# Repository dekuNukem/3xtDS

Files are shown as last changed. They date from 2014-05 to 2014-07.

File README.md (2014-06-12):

3xtDS
=====

The 3DS Streaming Console with External Control Interface, or 3xtDS, is a modified Nintendo 3DS console equipped with an capture card and an USB interface that allows the control of buttons, circle pad, and touch screen from an external source, as well as streaming high quality video of the content of both screen and sound back to the host to be recorded, or broadcast. This allows some very interesting applications such as interactive streaming on Twitch or other websites, gameplay automation, remote play over Internet, using alternative controllers, and much more.

Please see a short video of it in action: https://www.youtube.com/watch?v=9PZrJH7Z8KE

I want to thank u/velocikoopa for providing a console for me to work on, without him this project would be impossible.

Project gallery: http://imgur.com/a/ICxh5

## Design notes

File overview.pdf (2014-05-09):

# 3DS Streaming Console with External Control Interface

# Technical overview

## 1. Introduction

The 3DS Streaming Console with External Control Interface, or 3xtDS in short, is a modified Nintendo 3DS console equipped with an capture card and an USB interface that allows the control of buttons, circle pad, and touch screen from an external source, as well as streaming high quality video of the content of both screen and sound back to the host to be recorded, or broadcasted. This allows some very interesting applications such as interactive streaming on Twitch or other websites, gameplay automation, remote play over internet, using alternative controllers, and much more.

The construction of this project is relatively straight forward. A 3DS with capture card is taken apart, various contacts to the buttons, circle pad, and touchscreen is then brought out to be controlled by a microcontroller, who executes commands from USB serial communication.

Please note that this document is just a brief overview of several aspects of this project, not a step-by-step guide of making one from scratch. Unless you have some decent experience with analog/digital circuits, microcontroller programming, taking stuff apart and being able to put it back together again, I would not encourage you trying creating one yourself, since you’ll most likely break a expensive piece of gaming console.

## 2. Hardware Overview

The hardware aspect of this project is relatively simple: just take a 3DS apart and solder some wires on some test points. But first of all you have to obtain a 3DS with a capture card. One was kindly lent to be by Reddit user velocikoopa, and it was him that made the entire project possible. You can buy a new one, but it’s rather expensive. velocikoopa paid almost $600 for his 3DS with capture card. A much cheaper capture card-enhanced 2DS is coming out at $380. Although I haven’t seen it in person yet. (http://www.3dsvideocapture.com/product/40)

Before we start, something to keep in mind: Don’t forget to bring out the ground of the 3DS and connect it to your own circuit, otherwise 3DS will not respond to the control signals. And also 3DS uses 1.8V logic, so whenever I mention VCC it’s 1.8V.

Follow iFixit’s teardown (http://www.ifixit.com/Teardown/Nintendo+3DS+Teardown/5029) until you have the mother board out, be careful as there are a lot of small components and fragile ZIF flat cables. Look for buttons’ test points on the front side of the motherboard, namely TP85 for up, TP87 for left, TP91 for down, TP90 for right (this might be under the flat cable for the capture card, cut a little opening to access this test point), TP81 for select and TP80 for start. Three of the test points for A, B, X, Y are right in the middle of those four buttons, the other one is right above Y button. There is no test point for home button, but you can just solder a wire on the left pin of the button. Here is a picture of all the wires soldered in place:

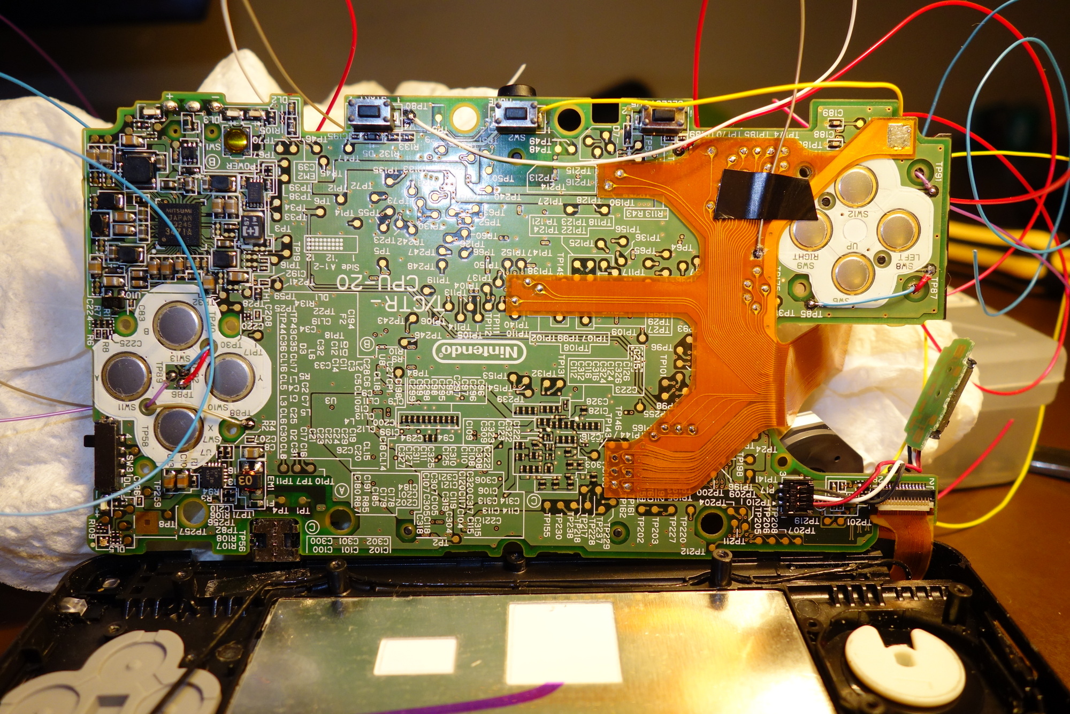
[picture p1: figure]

There are no test points for L and R shoulder buttons either. I soldered wire directly to each button itself, on the middle pin:

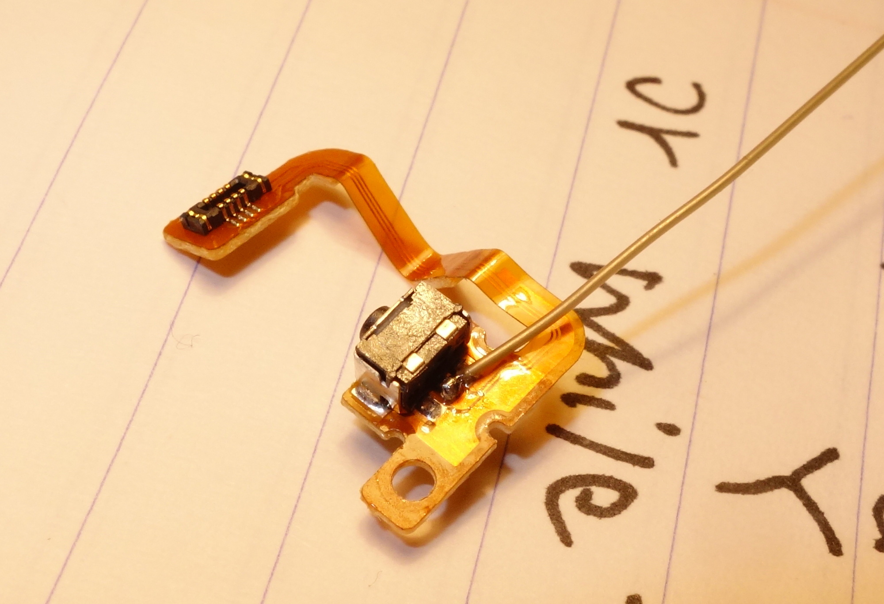
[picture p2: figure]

Now onto the circle pad. It is basically an potentiometer with two outputs, one for each axis. When looking at this picture:

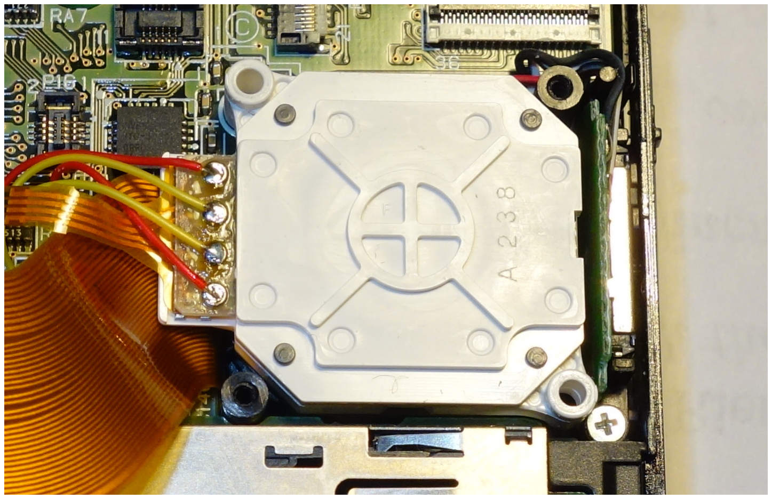
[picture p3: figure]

The pinout from top to bottom is: GND, x potential, VCC, y potential. To control the circle pad with microcontroller, simply desolder the potential output wires and feed them the DAC output from microcontroller instead. Range is from 0V to VCC.

Everything so far has been pretty trivial, buttons and circle pad. But now we face the biggest challenge: tricking 3DS into thinking someone is using the touch screen. 3DS uses a standard 4-wire interface, to get a general idea of how resistive touch screens work, I suggest taking a look at this document:

http://www.ti.com/lit/an/slaa384a/slaa384a.pdf

As with the method described in Section 1.3 the document:

3DS drives Y+ to VCC, Y- to ground, and measure the output at X+ for X coordinate. Similarly, driving X+ to VCC and X- to ground yield Y coordinate at Y+. To get a complete reading of X

Y–

Read X+

Y+ | Read Y+
X– | X+

VDrive

Figure 3. 4-Wire Touch Coordinate Reading and Y coordinate, X+, X-, Y+, Y- are rapidly switched between input and output, at around 200Hz.

I suggest getting a extra 4-pin flat cable so that you can interface with the touch screen input on the motherboard without destroying the socket:

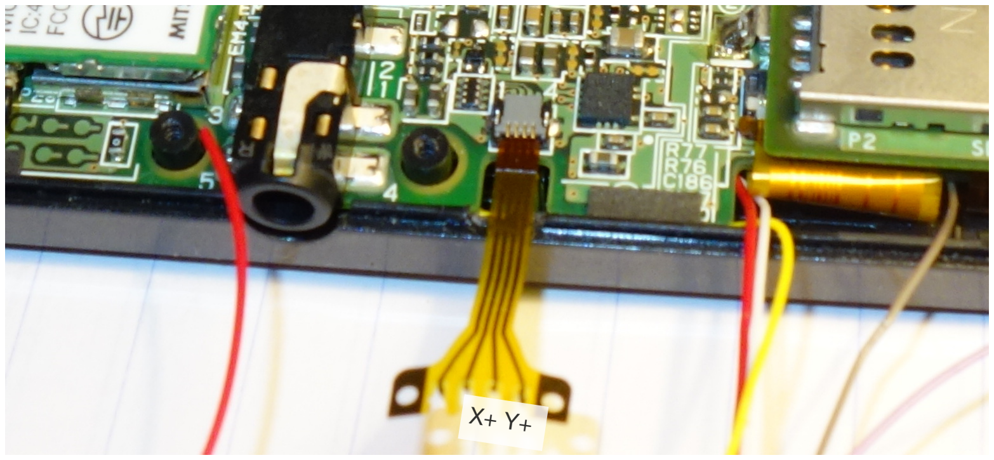
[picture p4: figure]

We only need the last two pins on the right in order to simulate a touch screen for 3DS, they are X+ and Y+ respectively.

The reading of the touch screen is interrupt based, as described in Section 1.2 of the document. Y+ pin is normally at VCC, which is pulled to ground when a touch occurs, generating a touch interrupt, and starting the sampling process.

To write X coordinates, you can tie the DAC output of microcontroller directly to X+ pin in series with a 10K resistor, so when X+ is in input mode, the DAC voltage is read, and when X+ is in output mode, the resistor prevents the current flow. Write 0V to 1.8V for coordinate 0 to 320.

For Y coordinates, the Y+ pin is tricker, since it also generates an interrupt, so some timing is required. After connecting it to DAC in series of a 1K resistor, pull it to ground to initiate touch interrupt, then monitor this pin using an on-board ADC. Once the Y+ pin has been switched to output (reading X coordinate), wait 500 microseconds, so now Y+ is in input mode, then write the Y coordinate to Y+ using the DAC, hold for 200 microseconds, then pull it down to ground again. Write 0V to 1.8V for coordinate 0 to 240.

The timing should look like this:

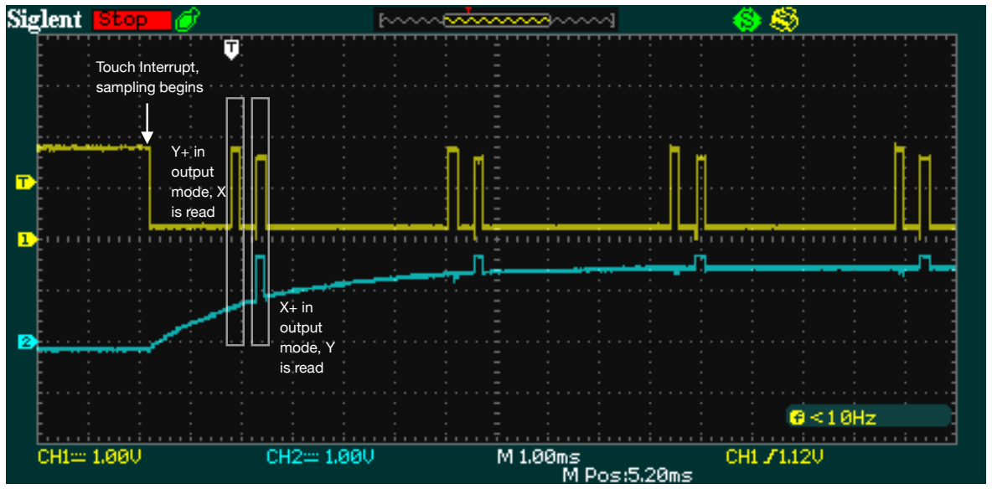
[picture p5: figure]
Touch Interrupt, sampling begins; X+ in output mode, Y is read; Y+ in output mode, X is read

Yellow is Y+, blue is X+

Now you have all the control wires of 3DS, all that’s left to do is hook them up to an microcontroller and have it control it for you! Please take a look at the eagle file for the control board.

## 3. The Control Board

All the wires that came out of 3DS end up in the control board, let at the mercy of the microcontroller, in this case a Teensy 3.1. You can use plain old Arduino as well, but make sure it has enough pins. Also notes that USB serial on Arduino is not as fast as 12Mbit/s full speed USB serial on Teensy 3.1.

The size of the board is quite large for what it is, I did this because of the limitation of the milling machine I’m using, so do feel free to shrink it down.

The circuit for the control board is pretty straightforward as well. All the buttons are active low, so pull them to ground to press them. One problem is the logic levels. 3DS uses 1.8V, while teensy uses 3.3V. I used a 74540 buffer as a level shifter. Power the chip with 1.8V, send 3.3V signal in, 1.8V signal comes out of the other end, and to 3DS.

Teensy 3.1 has a real DAC on A14, as well as a number of PWM pins. I used the real DAC to control the Y+ of touch screen, since it requires very fast response. PWM output can be filtered to create a DAC as well, albeit the tradeoff between rise time and high frequency component left in the output. I used 4 PWM DACs for circle pad X, circle pad Y, touch screen X(hence the slow rise time in blue channel in the above picture), as well as powering the logic switching chip.

I have also added a header for SPI and hardware serial pins, should you need to use those communication protocols.

## 3. Commands

Command | Example | Notes
cn x y | cn 127 200 | Circle pad nudge. Pushes circle pad to x, y, hold it there for c_pad_nudge_delay_ms, then release. x, y should be less than 255 and greater than 0. 127 is neutral position, greater than 127 for left/up, smaller than 127 for right/down.
ch x y | ch 20 127 | Circle pad hold. Hold circle pad at x, y. x, y range is same as circle pad nudge.
cr | cr | Circle pad release. Return circle pad to default location.
cd c_pad_nudge_delay_ms | cd 200 | Circle pad set nudge delay. Set how long the circle pad is held before being released when circle pad nudge is called.
tc x y | tc 133 70 | Touch screen click. Press down on touch screen at x, y, hold it there for touch_screen_click_delay_ms, then release. x should be within 320 y should be within 240

td touch_screen_click_delay_ms | td 200 | Touch screen set click delay. Set how long the touch screen is held before releasing when touch screen click is called.
bc [button] | bc a | Button click. Press down a button, hold it for button_click_delay_ms, then release. See next table for argument of buttons.
bh [button] | bh a | Button hold. Press down a button
br [button] | br a | Button release. Release a button
br | br | Button release all. Release all buttons. Note that this command has no arguments.
bd button_click_delay_ms | bd 100 | Button set click delay. Set how long a button is held down before being released when button click is called.
3DS Button | Argument for bc, bh and br:
A | a
B | b
X | x
Y | y
D-Pad Up | u
D-Pad Down | d
D-Pad Left | l
D-Pad Right | r
Left Shoulder | ls

Right Shoulder | rs
Start | st
Select | sl
Home | h

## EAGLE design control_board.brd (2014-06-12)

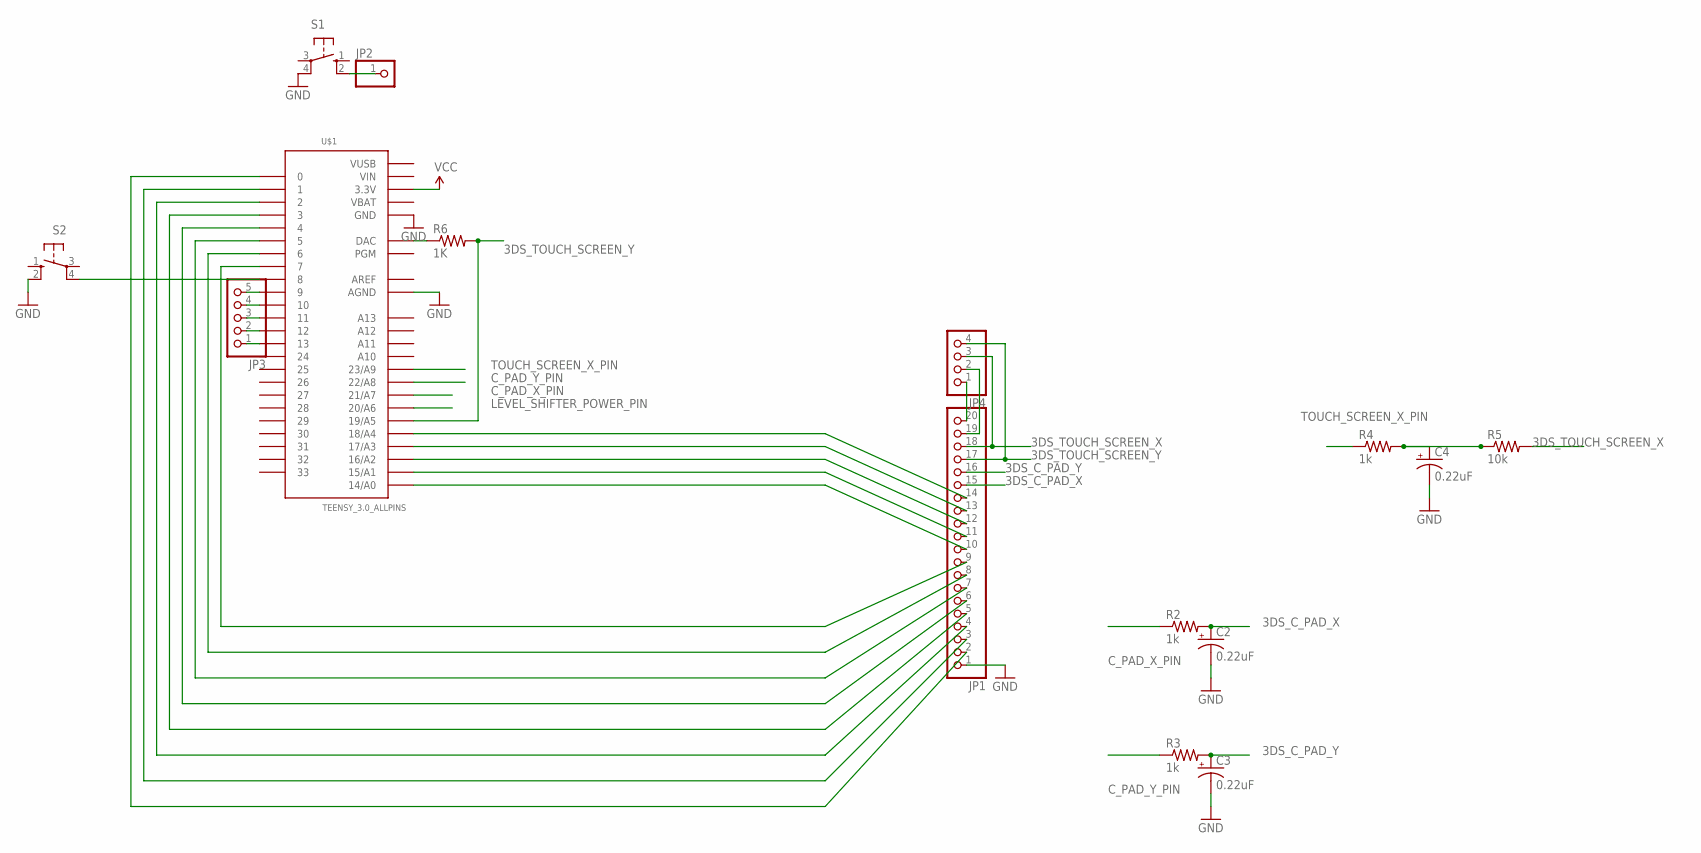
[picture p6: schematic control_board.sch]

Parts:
C2, C3, C4: 0.22uF; CPOL-RADIAL-10UF-25V
JP1: PINHD-1X20; 1X20
JP2: PINHD-1X1; 1X01
JP3: PINHD-1X5; 1X05
JP4: PINHD-1X4; 1X04
R2, R3, R4: 1k; 0207/7
R5: 10k; AXIAL-0.1
R6: 1K; 0207/7
S1, S2: 10-XX; B3F-10XX
U$1: TEENSY_3.0_ALLPINS

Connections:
3DS_C_PAD_X: C2.1 (+), JP1.15, R2.2
3DS_C_PAD_Y: C3.1 (+), JP1.16, R3.2
3DS_TOUCH_SCREEN_X: JP1.18, JP4.3, R5.P$2 (2)
3DS_TOUCH_SCREEN_Y: JP1.17, JP4.4, R6.2, U$1.19/A5
AREF: U$1.AREF
C_PAD_X_PIN: R2.1, U$1.21/A7
C_PAD_Y_PIN: R3.1, U$1.22/A8
GND: C2.2 (-), C3.2 (-), C4.2 (-), JP1.1, S1.4 (P1), S2.2 (S1), U$1.AGND, U$1.GND, U$1.GND1 (GND), U$1.GND2 (GND)
LEVEL_SHIFTER_POWER_PIN: U$1.20/A6
N0: C4.1 (+), R4.2, R5.P$1 (1)
unnamed: JP2.1, S1.2 (S1)
unnamed: JP1.10, U$1.14/A0
unnamed: JP1.11, U$1.15/A1
unnamed: JP1.12, U$1.16/A2
unnamed: JP1.13, U$1.17/A3
unnamed: JP1.2, U$1.0
unnamed: JP1.3, U$1.1
unnamed: JP1.4, U$1.2
unnamed: JP1.5, U$1.3
unnamed: JP1.6, U$1.4
unnamed: JP1.7, U$1.5
unnamed: JP1.8, U$1.6
unnamed: JP1.9, U$1.7
unnamed: R6.1, U$1.RESET (DAC)
unnamed: JP1.14, U$1.18/A4
unnamed: JP3.5, U$1.9
unnamed: JP3.4, U$1.10
unnamed: JP3.3, U$1.11
unnamed: JP3.2, U$1.12
unnamed: JP3.1, U$1.13
unnamed: JP1.20, JP4.1
unnamed: JP1.19, JP4.2
unnamed: S2.4 (P1), U$1.8
TOUCH_SCREEN_X_PIN: R4.1, U$1.23/A9
VBAT: U$1.VBAT
VCC: U$1.3.3V, U$1.3.3V1 (3.3V), U$1.3.3V2 (3.3V)
VIN: U$1.VIN
VUSB: U$1.VUSB

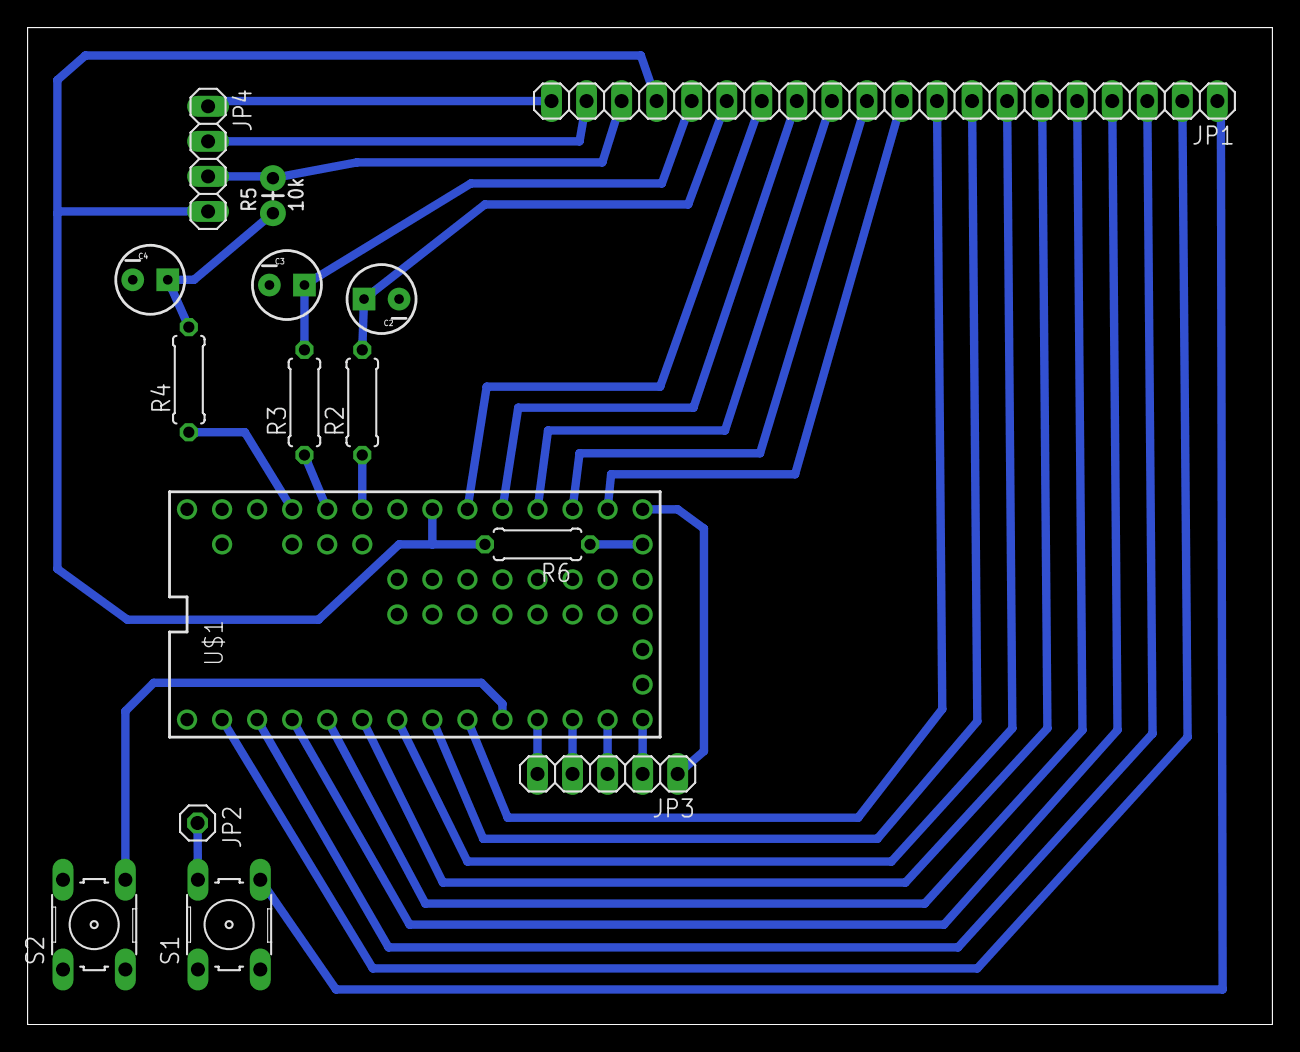
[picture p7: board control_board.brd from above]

Board: 2 copper layers, 90.2 x 72.3 mm, 15 parts (0 on the bottom side), 33 nets.

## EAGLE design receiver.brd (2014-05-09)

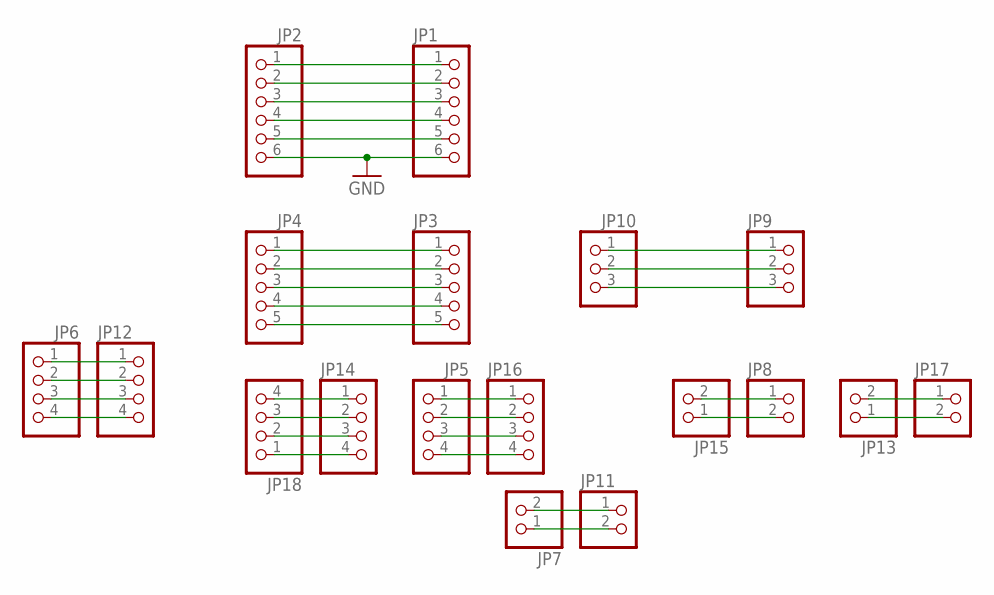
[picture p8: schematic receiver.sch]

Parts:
JP1, JP2: PINHD-1X6; 1X06
JP3, JP4: PINHD-1X5; 1X05
JP5, JP6, JP12, JP14, JP16, JP18: PINHD-1X4; 1X04
JP7, JP8, JP11, JP13, JP15, JP17: PINHD-1X2; 1X02
JP9, JP10: PINHD-1X3; 1X03

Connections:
GND: JP1.6, JP2.6
unnamed: JP1.1, JP2.1
unnamed: JP1.2, JP2.2
unnamed: JP1.3, JP2.3
unnamed: JP1.4, JP2.4
unnamed: JP1.5, JP2.5
unnamed: JP8.1, JP15.2
unnamed: JP3.1, JP4.1
unnamed: JP3.2, JP4.2
unnamed: JP3.3, JP4.3
unnamed: JP3.4, JP4.4
unnamed: JP3.5, JP4.5
unnamed: JP8.2, JP15.1
unnamed: JP7.2, JP11.1
unnamed: JP7.1, JP11.2
unnamed: JP6.1, JP12.1
unnamed: JP6.2, JP12.2
unnamed: JP6.3, JP12.3
unnamed: JP6.4, JP12.4
unnamed: JP5.1, JP16.1
unnamed: JP9.1, JP10.1
unnamed: JP9.2, JP10.2
unnamed: JP9.3, JP10.3
unnamed: JP5.2, JP16.2
unnamed: JP5.3, JP16.3
unnamed: JP5.4, JP16.4
unnamed: JP14.1, JP18.4
unnamed: JP14.2, JP18.3
unnamed: JP14.3, JP18.2
unnamed: JP14.4, JP18.1
unnamed: JP13.2, JP17.1
unnamed: JP13.1, JP17.2

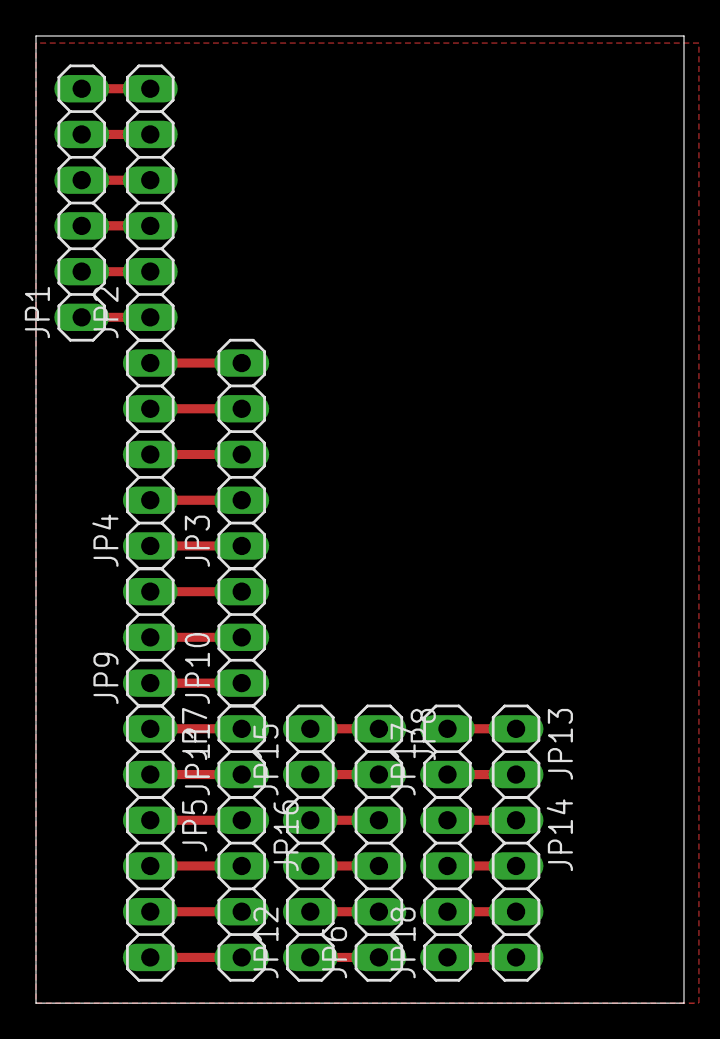
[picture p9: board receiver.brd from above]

Board: 2 copper layers, 36.0 x 53.7 mm, 18 parts (0 on the bottom side), 32 nets.

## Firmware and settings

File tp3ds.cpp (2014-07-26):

#include <stdint.h>
#include <stdio.h>
#define BUTTON_A_PIN 0
#define BUTTON_B_PIN 1
#define BUTTON_X_PIN 2
#define BUTTON_Y_PIN 3
#define BUTTON_RIGHT_SHOULDER_PIN 4
#define BUTTON_LEFT_SHOULDER_PIN 5
#define BUTTON_UP_PIN 6
#define BUTTON_DOWN_PIN 7
#define BUTTON_LEFT_PIN 14
#define BUTTON_RIGHT_PIN 15
#define BUTTON_START_PIN 16
#define BUTTON_SELECT_PIN 17
#define BUTTON_HOME_PIN 18
#define TOUCH_SCREEN_X_PIN 23
#define TOUCH_SCREEN_Y_PIN A14
#define TOUCH_SCREEN_Y_SENSE_PIN 19
#define C_PAD_X_PIN 21
#define C_PAD_Y_PIN 22
#define DEBUG_BUTTON_PIN 8
#define LED_PIN 13
#define C_PAD_DEFAULT_POTENTIAL 140
#define DAC_9_BIT_1V8 279
#define RECV_BUF_SIZE 64
#define BUTTON_PRESSED LOW
#define MINIMAL_DELAY_MS 10

char recv_buf[RECV_BUF_SIZE];
int32_t c_pad_nudge_delay_ms;
int32_t button_click_delay_ms;
int32_t touch_screen_click_delay_ms;

void setup()
{
	// Teensy USB serial always run at full USB speed of 12 Mbit/sec,
	// regardless of the argument.
    Serial.begin(9600);
    analogWriteResolution(9);
	analogReadResolution(10);
	// PWM frequency at 90KHz
	analogWriteFrequency(TOUCH_SCREEN_X_PIN, 90000);
	pinMode(DEBUG_BUTTON_PIN, INPUT_PULLUP);
	delay(1);
	pinMode(LED_PIN, OUTPUT);
	pinMode(BUTTON_A_PIN, OUTPUT);
	pinMode(BUTTON_B_PIN, OUTPUT);
	pinMode(BUTTON_X_PIN, OUTPUT);
	pinMode(BUTTON_Y_PIN, OUTPUT);
	pinMode(BUTTON_RIGHT_SHOULDER_PIN, OUTPUT);
	pinMode(BUTTON_LEFT_SHOULDER_PIN, OUTPUT);
	pinMode(BUTTON_UP_PIN, OUTPUT);
	pinMode(BUTTON_DOWN_PIN, OUTPUT);
	pinMode(BUTTON_LEFT_PIN, OUTPUT);
	pinMode(BUTTON_RIGHT_PIN, OUTPUT);
	pinMode(BUTTON_START_PIN, OUTPUT);
	pinMode(BUTTON_SELECT_PIN, OUTPUT);
	pinMode(BUTTON_HOME_PIN, OUTPUT);
	button_release_all();
	pinMode(C_PAD_X_PIN, OUTPUT);
	pinMode(C_PAD_Y_PIN, OUTPUT);
	c_pad_reset();
	button_click_delay_ms = 250;
    c_pad_nudge_delay_ms = 500;
    touch_screen_click_delay_ms = 100;
    digitalWrite(LED_PIN, HIGH);
    while(digitalRead(DEBUG_BUTTON_PIN) == HIGH)
    	Serial.read();
    digitalWrite(LED_PIN, LOW);
    pinMode(TOUCH_SCREEN_X_PIN, OUTPUT);
	pinMode(TOUCH_SCREEN_Y_PIN, OUTPUT);
    analogWrite(TOUCH_SCREEN_X_PIN, 0);
    disable_touch_screen();
}

// main loop, wait for commands from PC
void loop()
{
	if(get_serial_command(recv_buf, RECV_BUF_SIZE) != -1)
	{
		// c-pad nudge:  cn 127 240
		if(strncmp(recv_buf, "cn ", 3) == 0)
		{
			int16_t arg1_pos = goto_next_arg(0, recv_buf, RECV_BUF_SIZE);
			int16_t arg2_pos = goto_next_arg(arg1_pos, recv_buf, RECV_BUF_SIZE);
			int16_t x = atoi(recv_buf + arg1_pos);
			int16_t y = atoi(recv_buf + arg2_pos);
			c_pad_nudge(x, y, c_pad_nudge_delay_ms);
		}
		// c-pad hold: ch 127 240
		if(strncmp(recv_buf, "ch ", 3) == 0)
		{
			int16_t arg1_pos = goto_next_arg(0, recv_buf, RECV_BUF_SIZE);
			int16_t arg2_pos = goto_next_arg(arg1_pos, recv_buf, RECV_BUF_SIZE);
			int16_t x = atoi(recv_buf + arg1_pos);
			int16_t y = atoi(recv_buf + arg2_pos);
			c_pad_hold(x, y);
		}
		// c-pad release: cr
		if(strncmp(recv_buf, "cr\n", 3) == 0)
			c_pad_reset();
		/*	
		c-pad set nudge delay, aka how long the c-pad
		is held before releasing when c_pad_nudge is called
		cd 100
		*/
		if(strncmp(recv_buf, "cd ", 3) == 0)
		{
			int16_t arg1_pos = goto_next_arg(0, recv_buf, RECV_BUF_SIZE);
			int16_t new_delay = atoi(recv_buf + arg1_pos);
			new_delay > MINIMAL_DELAY_MS ? c_pad_nudge_delay_ms = new_delay : c_pad_nudge_delay_ms;
		}
		// touch screen click: tc 120 50
		if(strncmp(recv_buf, "tc ", 3) == 0)
		{
			int16_t arg1_pos = goto_next_arg(0, recv_buf, RECV_BUF_SIZE);
			int16_t arg2_pos = goto_next_arg(arg1_pos, recv_buf, RECV_BUF_SIZE);
			int16_t x = atoi(recv_buf + arg1_pos);
			int16_t y = atoi(recv_buf + arg2_pos);
			touch_screen_click(x, y, touch_screen_click_delay_ms);
		}
		// touch screen set click delay in ms: td 100
		if(strncmp(recv_buf, "td ", 3) == 0)
		{
			int16_t arg1_pos = goto_next_arg(0, recv_buf, RECV_BUF_SIZE);
			int16_t new_delay = atoi(recv_buf + arg1_pos);
			new_delay > MINIMAL_DELAY_MS ? touch_screen_click_delay_ms = new_delay : touch_screen_click_delay_ms;
		}
		// button click: bc a
		if(strncmp(recv_buf, "bc ", 3) == 0)
		{
			int16_t arg1_pos = goto_next_arg(0, recv_buf, RECV_BUF_SIZE);
			button_click(get_button_pin(recv_buf + arg1_pos), button_click_delay_ms);
		}
		// button hold: bh a
		if(strncmp(recv_buf, "bh ", 3) == 0)
		{
			int16_t arg1_pos = goto_next_arg(0, recv_buf, RECV_BUF_SIZE);
			button_press(get_button_pin(recv_buf + arg1_pos));
		}
		// button release: br a
		if(strncmp(recv_buf, "br ", 3) == 0)
		{
			int16_t arg1_pos = goto_next_arg(0, recv_buf, RECV_BUF_SIZE);
			button_release(get_button_pin(recv_buf + arg1_pos));
		}
		// button release all: br\n
		if(strncmp(recv_buf, "br\n", 3) == 0)
			button_release_all();

		// button set click delay in ms: bd 100
		if(strncmp(recv_buf, "bd ", 3) == 0)
		{
			int16_t arg1_pos = goto_next_arg(0, recv_buf, RECV_BUF_SIZE);
			int16_t new_delay = atoi(recv_buf + arg1_pos);
			new_delay > MINIMAL_DELAY_MS ? button_click_delay_ms = new_delay : button_click_delay_ms;
		}
	}
}

void button_click(int8_t button_pin, int16_t button_delay)
{
	button_press(button_pin);
	delay(button_delay);
	button_release(button_pin);
	delay(20);
}

void button_press(int8_t button_pin)
{
	pinMode(button_pin, OUTPUT);
	digitalWrite(button_pin, BUTTON_PRESSED);
}

void button_release(int8_t button_pin)
{
	pinMode(button_pin, INPUT);
}

void button_release_all()
{
	button_release(BUTTON_A_PIN);
	button_release(BUTTON_B_PIN);
	button_release(BUTTON_X_PIN);
	button_release(BUTTON_Y_PIN);
	button_release(BUTTON_RIGHT_SHOULDER_PIN);
	button_release(BUTTON_LEFT_SHOULDER_PIN);
	button_release(BUTTON_UP_PIN);
	button_release(BUTTON_DOWN_PIN);
	button_release(BUTTON_LEFT_PIN);
	button_release(BUTTON_RIGHT_PIN);
	button_release(BUTTON_START_PIN);
	button_release(BUTTON_SELECT_PIN);
	button_release(BUTTON_HOME_PIN);
}

int32_t goto_next_arg(int16_t current_pos, char* buf, int16_t size)
{
	while(current_pos < size && buf[current_pos] != ' ')
		current_pos++;

	while(current_pos < size && buf[current_pos] == ' ')
		current_pos++;
	return current_pos;
}

// get a complete command from serial
int8_t get_serial_command(char buf[], int16_t size)
{
	if(Serial.available())
	{
		int16_t count = 0;
		memset(buf, 0, size);
		char c;
		while(1)
			if(Serial.available())
			{
				c = Serial.read();
				// ignore carriage return
				if(c == '\r')
					continue;
				if(count < size - 1)
					buf[count] = c;
				count++;
				if(c == '\n')
					return 0;
			}
	}
	else
		return -1;
}

void c_pad_nudge(uint16_t x, uint16_t y, int16_t duration_ms)
{
	c_pad_hold(x, y);
	delay(duration_ms);
	c_pad_reset();
}

void c_pad_hold(uint16_t x, uint16_t y)
{
	if(x > 255 || y > 255)
		return;
	analogWrite(C_PAD_X_PIN, x);
	analogWrite(C_PAD_Y_PIN, y);
}

void c_pad_reset()
{
	analogWrite(C_PAD_X_PIN, C_PAD_DEFAULT_POTENTIAL);
	analogWrite(C_PAD_Y_PIN, C_PAD_DEFAULT_POTENTIAL);
}

void touch_screen_click(uint16_t x, uint16_t y, int16_t duration_ms)
{
	if(x <= 0 || y <= 0 || x > 320 || y > 240)
		return;
	int16_t x_potential = ((double)x / 320) * 320;
	int16_t y_potential = ((double)y / 240) * 320;
	
	y_potential -= (((double)(y_potential)) * 0.257 - 29);
	x_potential -= (((double)(x_potential)) * 0.066 - 7);

	analogWrite(TOUCH_SCREEN_X_PIN, x_potential);
	enable_touch_screen();
	int32_t start = millis();
	while(millis() - start < duration_ms)
	{
		// wait until Y+ pin is in output mode
		while(analogRead(TOUCH_SCREEN_Y_SENSE_PIN) < 512);
		delayMicroseconds(490);
		// now Y+ pin is in input mode, write the value
		analogWrite(TOUCH_SCREEN_Y_PIN, y_potential);
		delayMicroseconds(180);
		// pull Y+ down again to keep interrupt going
		enable_touch_screen();
	}
	disable_touch_screen();
	analogWrite(TOUCH_SCREEN_X_PIN, 0);
	delay(50);
}

void disable_touch_screen()
{
	analogWrite(TOUCH_SCREEN_Y_PIN, DAC_9_BIT_1V8);
}

// pull Y+ pin low to initialize 3DS's touch interrupt
void enable_touch_screen()
{
	analogWrite(TOUCH_SCREEN_Y_PIN, 0);
}

int8_t get_button_pin(char* buf)
{
	if(strncmp(buf, "a\n", 2) == 0)
		return BUTTON_A_PIN;
	if(strncmp(buf, "b\n", 2) == 0)
		return BUTTON_B_PIN;
	if(strncmp(buf, "x\n", 2) == 0)
		return BUTTON_X_PIN;
	if(strncmp(buf, "y\n", 2) == 0)
		return BUTTON_Y_PIN;
	// right shoulder
	if(strncmp(buf, "rs\n", 3) == 0)
		return BUTTON_RIGHT_SHOULDER_PIN;
	// left shoulder
	if(strncmp(buf, "ls\n", 3) == 0)
		return BUTTON_LEFT_SHOULDER_PIN;
	if(strncmp(buf, "u\n", 2) == 0)
		return BUTTON_UP_PIN;
	if(strncmp(buf, "d\n", 2) == 0)
		return BUTTON_DOWN_PIN;
	if(strncmp(buf, "l\n", 2) == 0)
		return BUTTON_LEFT_PIN;
	if(strncmp(buf, "r\n", 2) == 0)
		return BUTTON_RIGHT_PIN;
	// start
	if(strncmp(buf, "st\n", 3) == 0)
		return BUTTON_START_PIN;
	// select
	if(strncmp(buf, "sl\n", 3) == 0)
		return BUTTON_SELECT_PIN;
	// home
	if(strncmp(buf, "h\n", 2) == 0)
		return BUTTON_HOME_PIN;
	else
		return -1;
}

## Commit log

2014-06-12 schematic update
    [control_board.brd, control_board.sch]
2014-07-26 “optimization”

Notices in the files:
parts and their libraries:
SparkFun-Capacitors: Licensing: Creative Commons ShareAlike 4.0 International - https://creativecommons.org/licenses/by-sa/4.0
